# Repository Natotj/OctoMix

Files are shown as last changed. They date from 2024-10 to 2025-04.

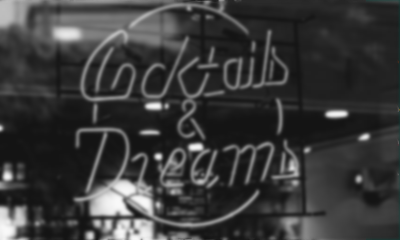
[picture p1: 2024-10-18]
Main_Programming/Display/Design_Elements/Symbols/Hintergrund weichgezeichnet.png

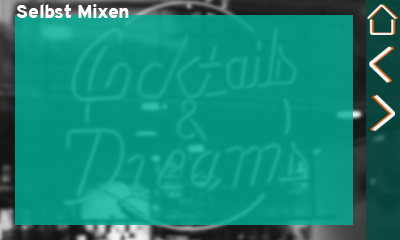
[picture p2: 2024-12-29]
Main_Programming/Display/Design_Elements/Pages/Self Mixing.png

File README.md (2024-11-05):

# OctoMix

Code and 3D parts for a diy cocktailmixer powerd by Arduino, EV3 and Nextion Dislplay. Many Parts are (or will be) 3D printed.

# NatotjEnglish.error

- Vent = valve

# Specs
- Arduiono Uno R3
- Lego Mindsorms EV3 31313
  - With 2 motors from the Lego Mindsorms NXT
  - Build with many other Lego technic parts
  - Programmed with the EV3 Lab (https://education.lego.com/de-de/downloads/retiredproducts/mindstorms-ev3-lab/software/)
- Nextion Display NX4024K032_011

# Disclaimer

All the content from this repo is for private use only. Use at your own risk!

# Contact

### E-Mail: 
- Natos.naz@gmail.com
- lama.customs@gmail.com

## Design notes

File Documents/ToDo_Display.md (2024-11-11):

### Cocktails

# Options 
- "selbst mixen" (mix yourself)
- Shots
- Pause, weiter, stopp (pause, continue, stop)
- zurück (back)

# Technical Options
- Ventil belegung (Doppelbelegung ausschließen) (valve assignment)
- Viskussität (von Standart) (viscosity)
- Glasgröße (glas size)
- Mixlänge (mix duration)

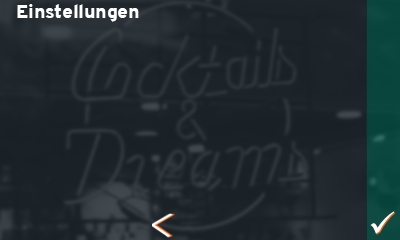
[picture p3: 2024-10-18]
Main_Programming/Display/Design_Elements/Pages/SET b.png

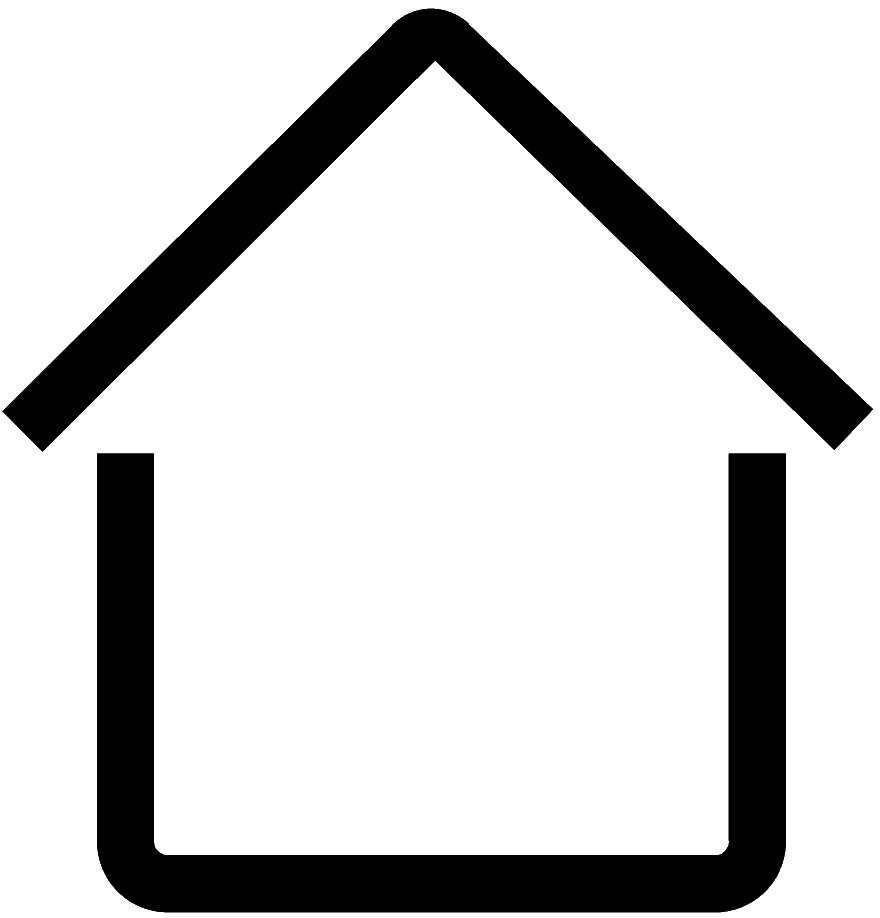
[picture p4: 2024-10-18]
Main_Programming/Display/Design_Elements/Symbols/Home.png

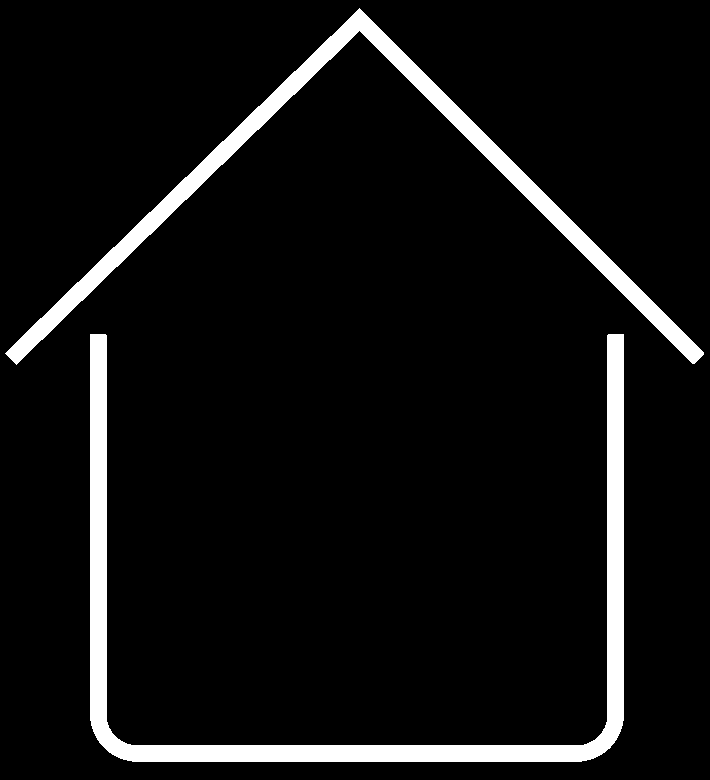
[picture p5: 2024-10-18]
Main_Programming/Display/Design_Elements/Symbols/Home.bmp

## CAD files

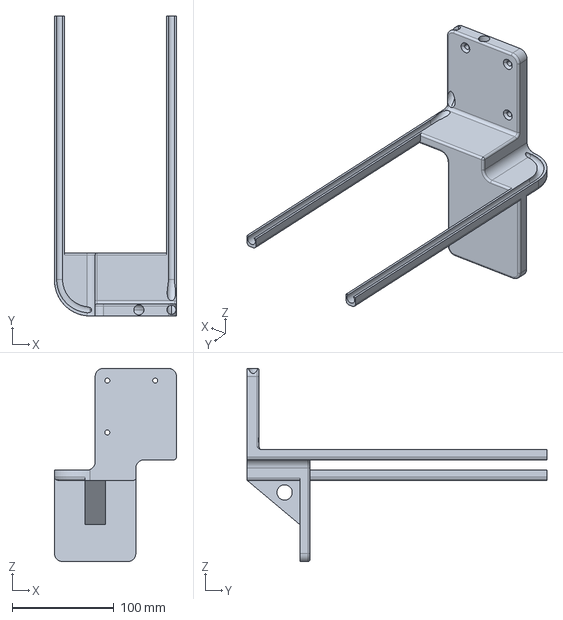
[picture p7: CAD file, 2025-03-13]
Main_Construction/3D-Print/flaschenhalter_asm.stp
120.0 x 295.0 x 190.0 mm

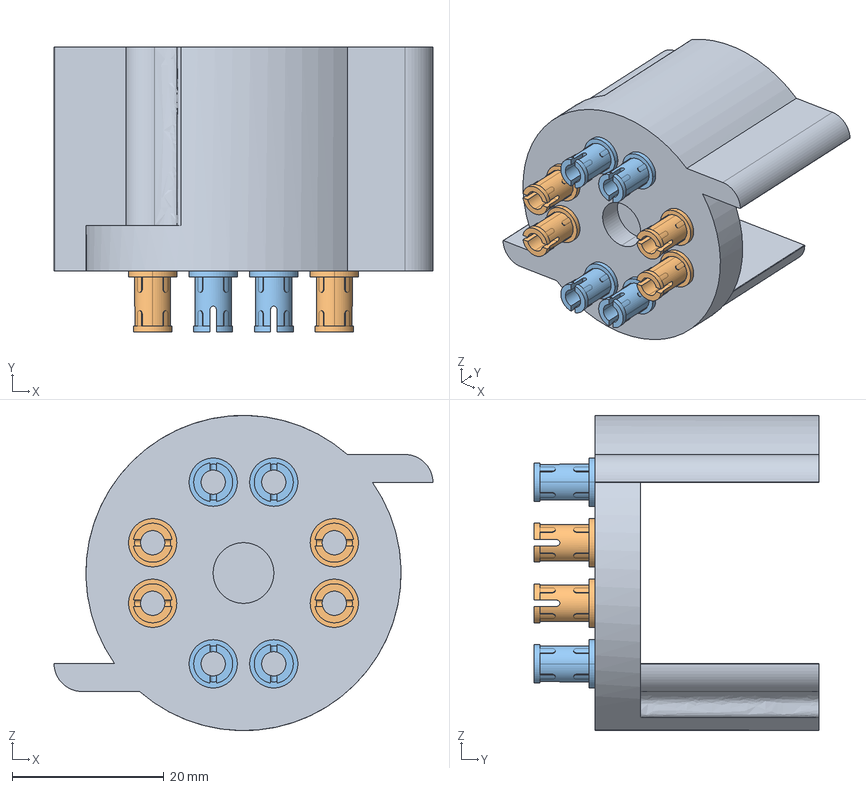
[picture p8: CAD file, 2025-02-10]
Main_Construction/3D-Print/ev3_zange_mit_pins_asm.stp
49.9 x 37.5 x 41.5 mm
EV3_ZANGE_AF0
LEGO_TECHNIC_FRICTION_PIN_AF0
LEGO_TECHNIC_FRICTION_PIN_AF1
LEGO_TECHNIC_FRICTION_PIN_AF2
LEGO_TECHNIC_FRICTION_PIN_AF3
LEGO_TECHNIC_FRICTION_PIN_AF4
LEGO_TECHNIC_FRICTION_PIN_AF5
LEGO_TECHNIC_FRICTION_PIN_AF6
LEGO_TECHNIC_FRICTION_PIN_AF7

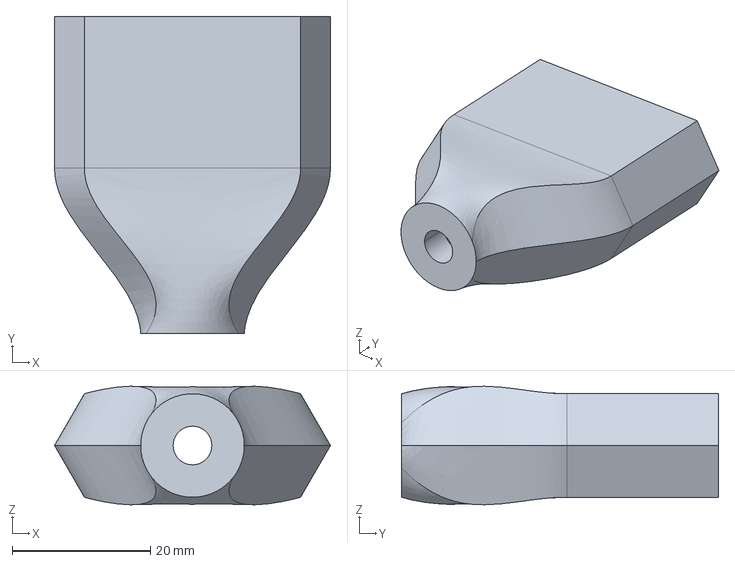
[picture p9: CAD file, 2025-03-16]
Main_Construction/3D-Print/schraubkopf.stp
40.0 x 46.0 x 17.2 mm

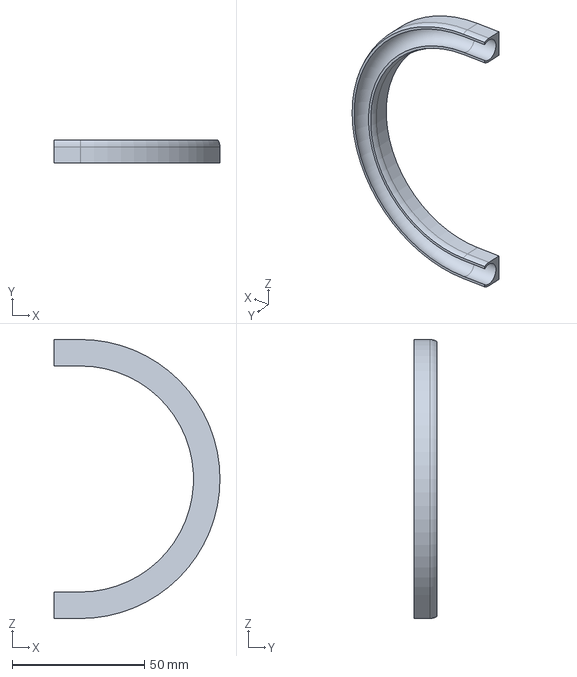
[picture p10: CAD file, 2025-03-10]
Main_Construction/Flaschenhalter/schlauchbogen.stp
62.7 x 8.50 x 105.3 mm

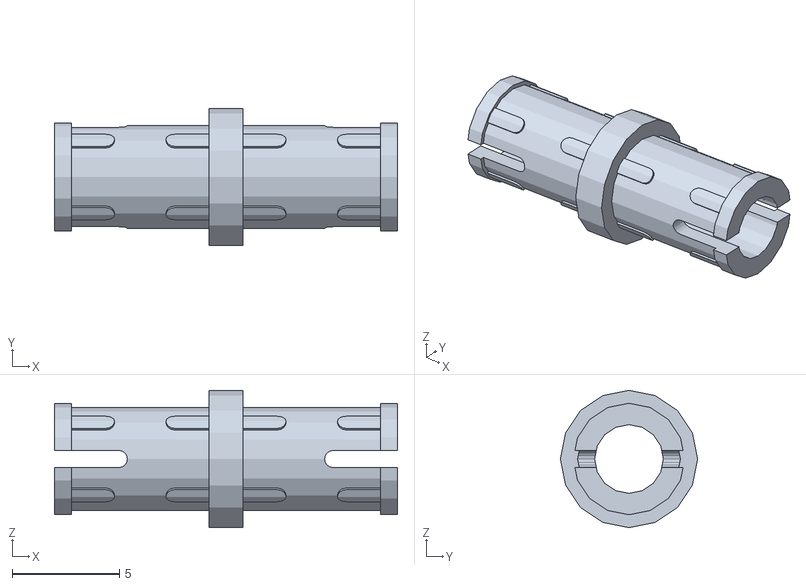
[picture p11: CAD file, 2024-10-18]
Main_Construction/Lego_tec_Pin_friction.stl
16.0 x 6.40 x 6.40

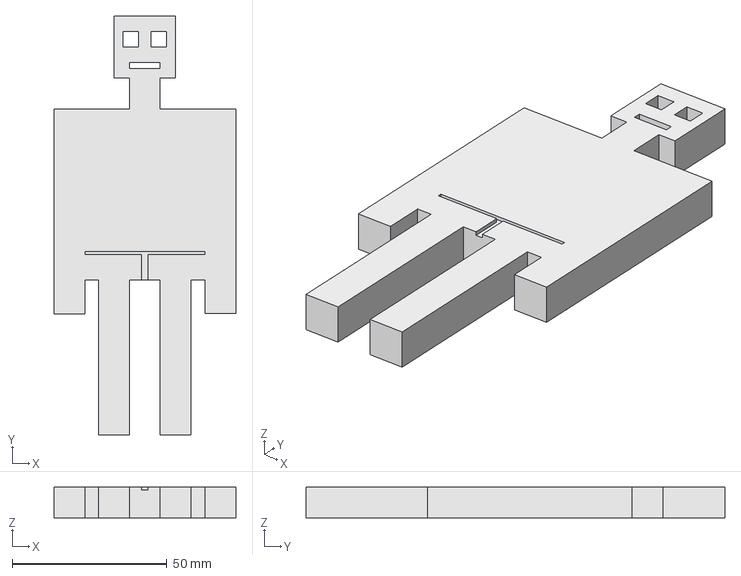
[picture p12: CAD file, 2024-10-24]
Main_Construction/TopSecret/alen.step
58.6 x 135.3 x 10.0 mm

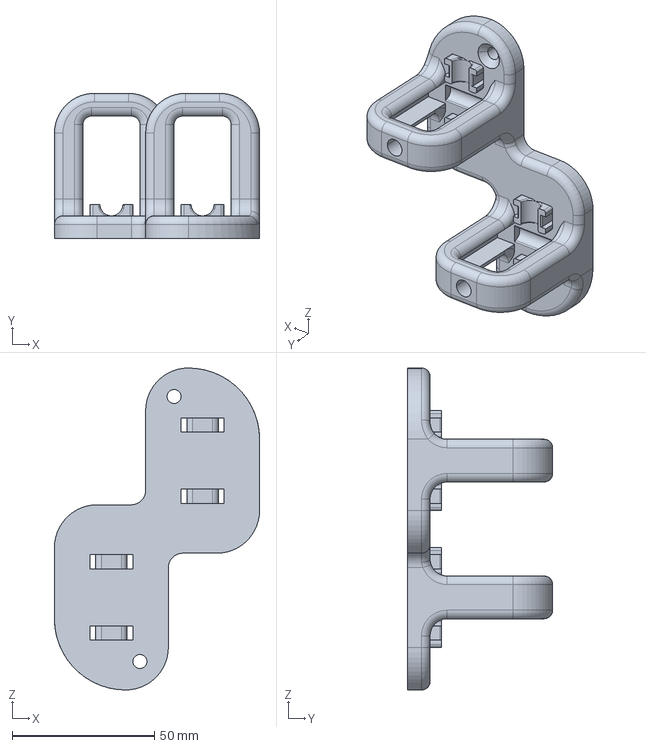
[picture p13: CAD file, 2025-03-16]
Main_Construction/3D-Print/valve_double_baseplate_v3.stp
72.0 x 51.0 x 113.0 mm

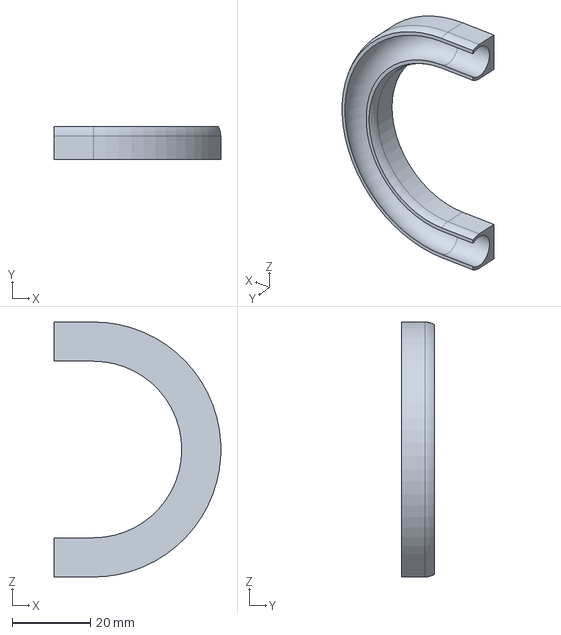
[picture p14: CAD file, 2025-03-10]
Main_Construction/3D-Print/schlauchbogen.stp
42.5 x 8.50 x 65.0 mm

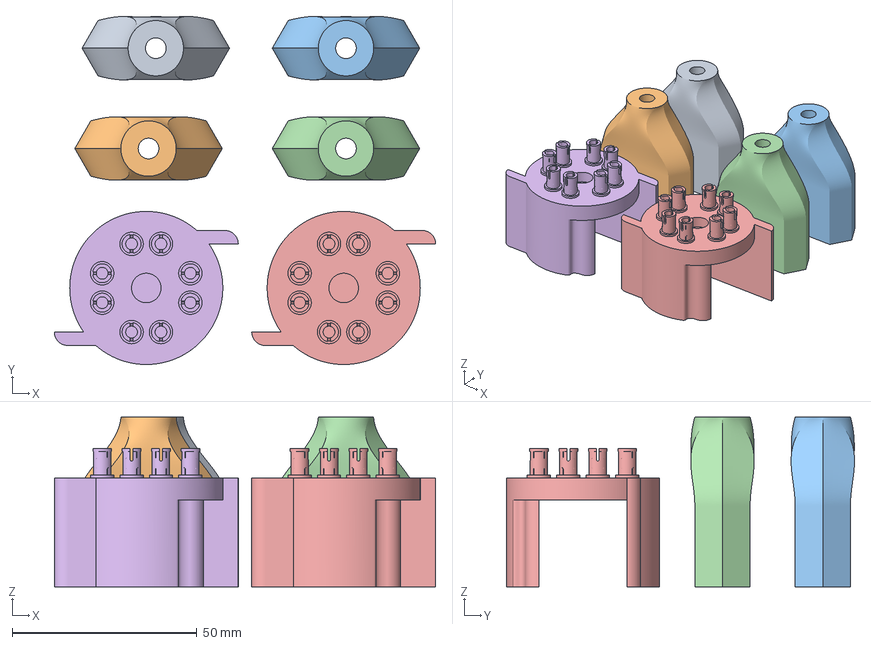
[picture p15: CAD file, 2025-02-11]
Main_Construction/3D-Print/EV3_Zange und Ventil Kopf.3mf
103.3 x 94.2 x 45.9 mm
schraubkopf
ev3_zange_mit_pins_asm

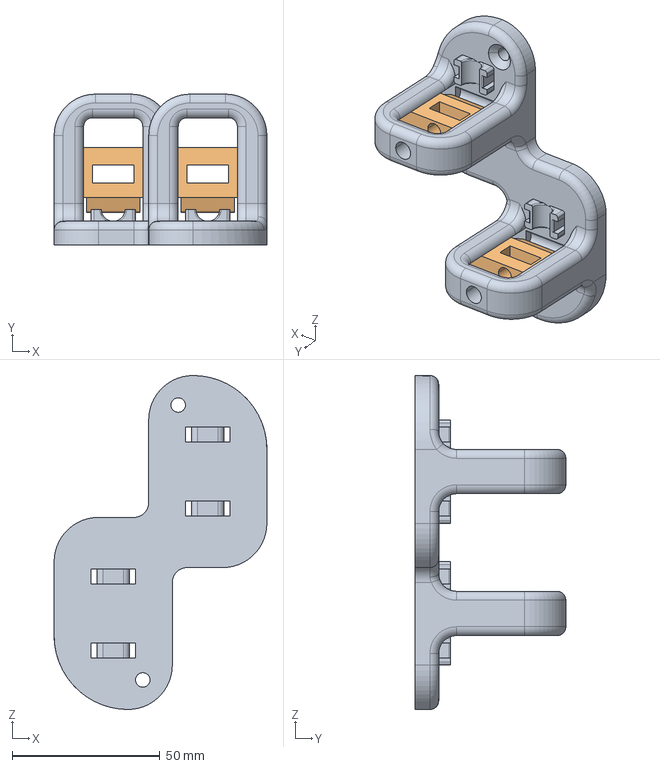
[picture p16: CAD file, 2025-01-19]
Main_Construction/3D-Print/Valve_V3.stp
72.0 x 51.0 x 113.0 mm
VALVE_DOUBLE_BASEPLATE
KLEMPLATTE_V3 x 2

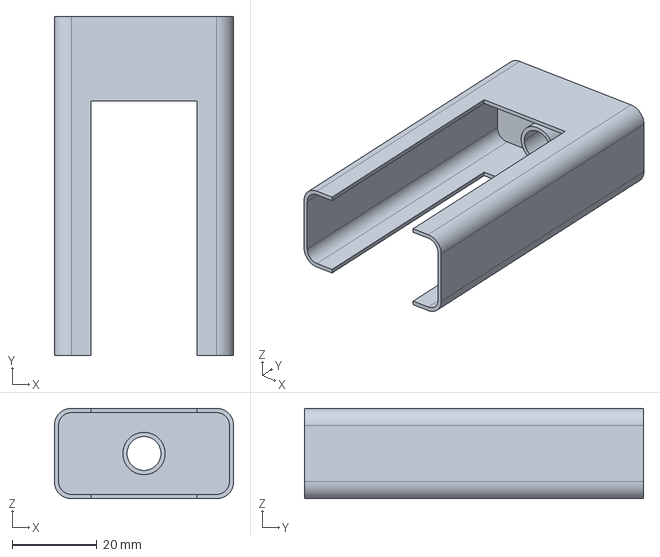
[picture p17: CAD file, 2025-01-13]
Main_Construction/3D-Print/montagehilfe_ltkol0001.stp
42.3 x 80.0 x 21.3 mm

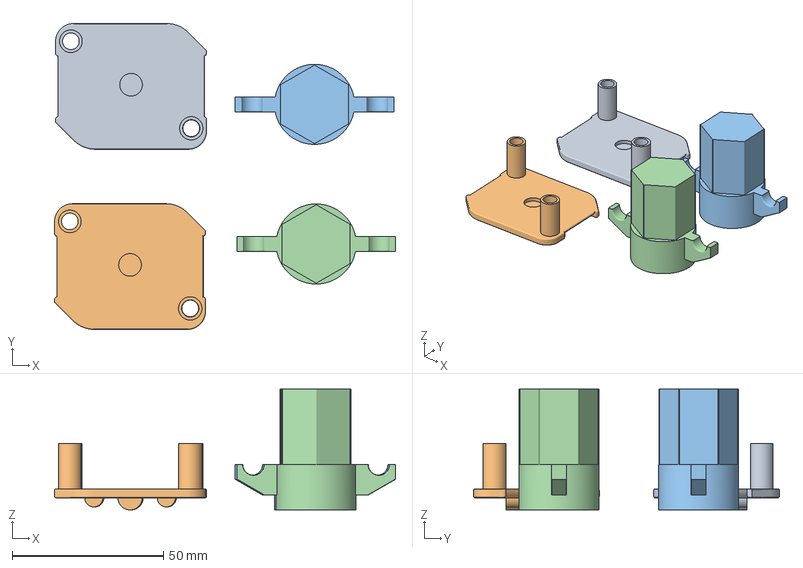
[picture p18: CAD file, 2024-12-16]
Main_Construction/3D-Print/Double Valve all components.3mf
112.7 x 101.1 x 40.0 mm
valve_clampplate
valve_head

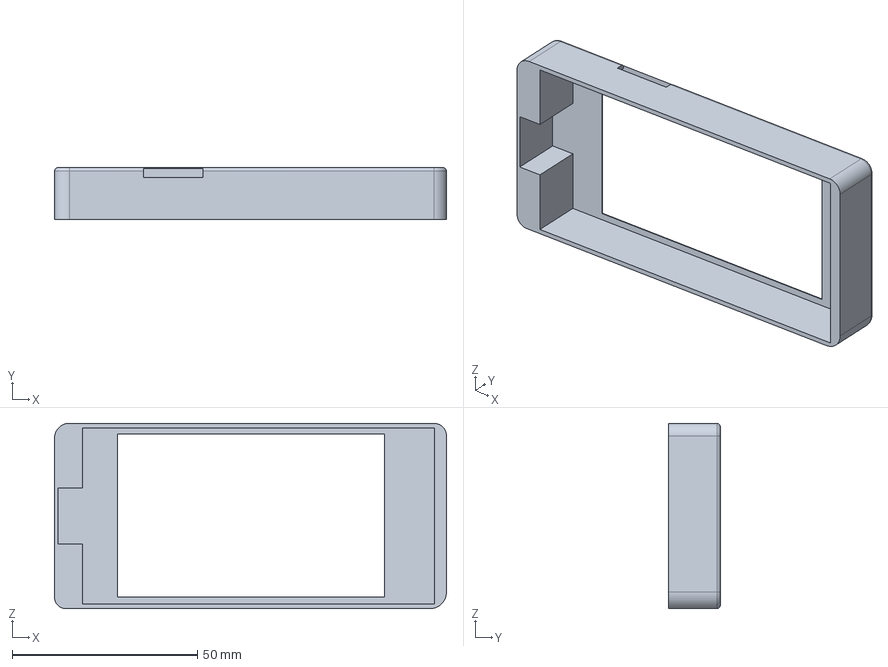
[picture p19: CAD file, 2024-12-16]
Main_Construction/3D-Print/display_braket.stp
105.7 x 14.0 x 50.0 mm

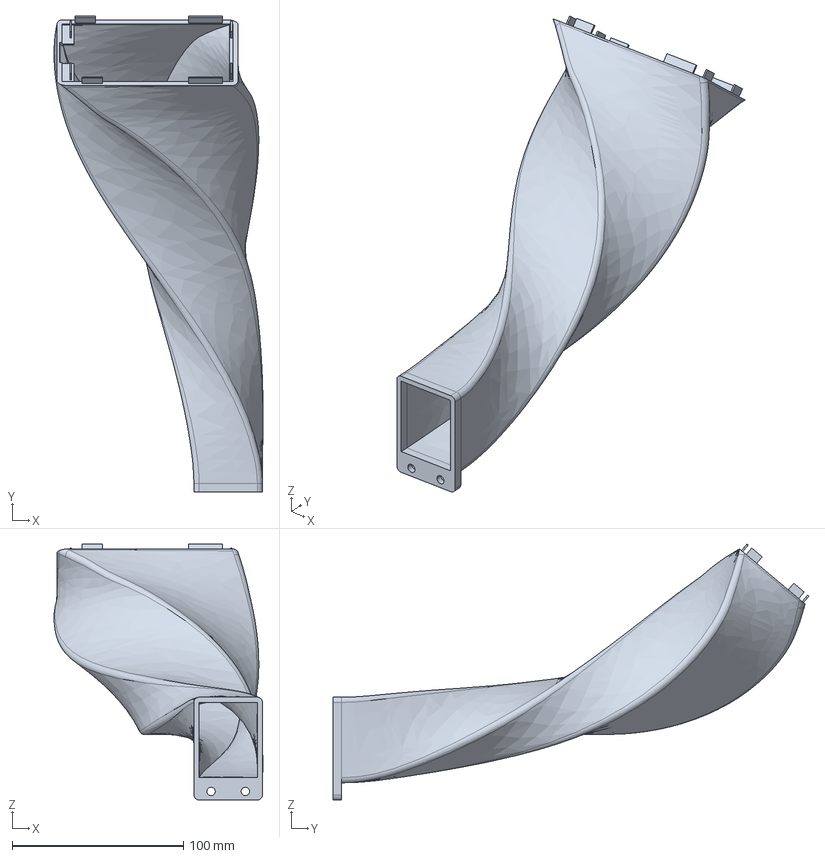
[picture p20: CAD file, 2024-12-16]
Main_Construction/3D-Print/hmi.stp
122.0 x 277.9 x 149.4 mm

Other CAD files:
Main_Construction/3D-Print/montagehilfe_loetkolben.3mf
Main_Construction/3D-Print/Double Valve white.3mf
Main_Construction/3D-Print/ultrasonic_hc-sr04_-_face_mount.stp
Main_Construction/3D-Print/ev3_stop.stp
Main_Construction/3D-Print/Ultrasonic_Mount_upper_part.stp
Main_Construction/3D-Print/Valve_V3.3mf
Main_Construction/3D-Print/ev3_stop and Display braket and HMI top part.3mf
Main_Construction/3D-Print/flaschenhalter_asm.3mf
Main_Construction/3D-Print/hmi-top-part.stp
Main_Construction/3D-Print/ultrasonic_hc-sr04_-_face_mount.3mf
Main_Construction/TopSecret/alen.FCStd
Main_Construction/Ultrasonic_HC-SR04_-_FACE_MOUNT.stl

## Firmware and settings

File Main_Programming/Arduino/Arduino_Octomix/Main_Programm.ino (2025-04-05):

//////////////////////////////////////////////////////////////
//          Main Program wich needs to be run
/////////////////////////////////////////////////////////////
// lokale Variablen
int i = 0;

void loop() {

//// Standby
  Display_Com();
  EV3_Com(EV3_STOP);
  EV3_Distance();
  temperatureRead();

int a[6] = {6, 8, 5, 9, 7, 10};
  while(true){
    for(i=0; i<6; i++){
      Serial.println(a[i]);
      Distance_Controll(valveDistance[a[i]-1]);
      //Distance_Controll(valveDistance[5-1]);
      Serial.println("angekommen");
      delay(2000);
      /*Distance_Controll(valveDistance[7-1]);
      Serial.println("angekommen");
      delay(2000);*/
    }
  }
// Programm zu Testzwecken für den Main Ablauf
  if(testRun == true){
   crsMix[0] = 0xF;  //15
    crsMix[1] = 0x4;  //04
    crsMix[2] = 0x15; //21
    crsMix[3] = 0x2; //02
    crsMix[4] = 0xE; //14
    crsMix[5] = 0x04; //04
    crsMix[6] = 0x1B; //27
    crsMix[7] = 0x5; //05
    crsMix[8] = 0x3; //03
    crsMix[9] = 0x14; //20
    crsMix[10] = 0x0; //0
    crsMix[11] = 0x0; //0
    crsMix[12] = 0x0; //0
    crsMix[13] = 0x0; //0
    crsMix[14] = 0x0; //0
    crsMix[15] = 0x0; //0
    crsMix[16] = 0x4; //4
    crsMix[17] = 0x0; //0
    isMixing = true;
  }

//// Ablauf Cocktail Mixen

  if(isMixing == true){ // Wenn Cocktail gemixt werden soll. isMixing wird von Display_Com gesetzt.
    //wann shaken?
    shake1 = crsMix[15];
    shake2 = crsMix[16];

    Progress_Bar();

    for(i=0; i<14; i+=2){ //stimmt die 14??
      printLine("New V");

      valveNum = crsMix[i];
      volume = crsMix[i+1];

      if (valveNum != 0){
        //zum Ventil fahren
        if(testRun == false) Distance_Controll(valveDistance[(valveNum+1)/2]); // gibt den aufgerundeten halbierten wert an valveDistance weiter an distance controll um dorthin zu fahren
        else Expanded_delay(5*1000);

        printLine("am Vent");
        Progress_Bar();  

        valveMove(valveNum); //Ventil öffnen
        Progress_Bar();
      
        //Pumpe
        digitalWrite(PUMP, HIGH); // Pumpe anschalten
        Expanded_delay(volume/flowrate * 1000); // richtige Zeit warten
        digitalWrite(PUMP, LOW); //Pumpe ausschalten
        Progress_Bar();
       
        valveMove(valveNum); //Ventil schließen
        Progress_Bar();

        //Shanken Wenn i/2+1=shake1 oder =shake2 dann shaken
        if((i/2+1)==shake1 || (i/2+1)==shake2) {
          digitalWrite(SHAKER, HIGH); // shaken an
          Progress_Bar(); 
          Expanded_delay(10*1000); // watet bis i größer als die wartezeit ist. (x in sek * 1000)
          digitalWrite(SHAKER, LOW); // shaken aus
        }
      }
    }
    // Nachricht an Display, dass Cocktail fertig
    Display_Write_Number("Home.isMixing.val=", 0);
    isMixing = false;
  }

  if(uploadToNextionDisplay == true) upload_to_display(); //Upload a Program to the Nextion display

  //Programm zum Testen von LED Werten der Übertragung
    /*while(true){
        delay(4000);
      int i;
      for(i=0; i < 9; i++) {
        analogWrite(LED, EV3_COM[i]);
        Serial.println(i);
        delay(4000);
      }
    }*/
}

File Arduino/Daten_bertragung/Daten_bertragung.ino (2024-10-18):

#define LCD_RS 4
#define LCD_E 7
#define LCD_D4 8
#define LCD_D5 9
#define LCD_D6 10
#define LCD_D7 11
#define JSTICK_VRX 3
#define JSTICK_VRY 4
#define JSTICK_SW 2
#define LED 6
#define USONIC_TRIG 1
#define USONIC_ECHO 0

int a[11]={0, 2, 7, 11, 15, 21, 35, 60, 95, 140, 255};
// EV3 Werte: 3-5, 8-10, 12-14, 15-17, 18-20, 23-25, 28-31, 33-35, 38-40, 44-46
// Befehle: 0 - STOPP
//          1 - Vorwärts schnell
//          2 - Vorwärts mittel
//          3 - Vorwärts langsam
//          4 - Rückwärts schnell
//          5 - Rückwärts mitttel
//          6 - Rückwärts langsam
//          7 - Ventil rear open
//          8 - Ventil front open
//          9 - Ventil rear close
//         10 - Ventil front close
//int a[10]={3, 10, 22, 40, 64, 93, 127, 165, 207, 255}; alte werte
int w=0;
String save="";
String save2="";
int test=0;
void setup() {
  // put your setup code here, to run once:
  Serial.begin(9600);
  pinMode(LED, OUTPUT);
  delay(5000);
}

void loop() {
  // put your main code here, to run repeatedly:
  /*
  Serial.println("vor"); //vor
  analogWrite(DIODE_ROT, 7);
  delay(1000);

  Serial.println("0"); 
  analogWrite(DIODE_ROT, 0);
  delay(500);

  Serial.println("Ventil 1");
  analogWrite(DIODE_ROT, 80);
  delay(1000);

  Serial.println("0");
  analogWrite(DIODE_ROT, 0);
  delay(500);


  Serial.println("zurück"); //zurück
  analogWrite(DIODE_ROT, 25);
  delay(1000);
  
  Serial.println("Ventil 2");
  analogWrite(DIODE_ROT, 200);
  delay(1000);

    Serial.println("0");
  analogWrite(DIODE_ROT, 0);
  delay(500);
*/
//analogWrite(LED, a[7]);
delay(500);
  for(int i=0; i<=10; i++)
  {
    //i=random(0,10);
    analogWrite(LED, a[i]);
    delay(5000);
    analogWrite(LED, 0);
    Serial.print(i);
    Serial.println();
    delay(50);
  } 
/*  if(Serial.available()>0)
  {
    while(Serial.available()>0)
    {
      w=Serial.read();
      w=w-48;
      save+=w;
      delay(30);
    }
    w=save.toInt();
    save="";
    analogWrite(LED, w);
    Serial.print("LED auf Wert:");
    Serial.println(w);
  }
*/

}

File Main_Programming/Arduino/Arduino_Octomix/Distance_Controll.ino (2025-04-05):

void Distance_Controll(float setPoint) {
  //Funktion um den EV3 über das gewünschte Ventil zu fahren. setPoint gibt den gewünschten Abstand zwischen US-Sensor und EV3 an. deltaErlaubt steuert die zulässige abweichung.
// PID-Parameter
  float Kp = 0.43*1.5;
  float Ki = 0.14*1.5;
  float Kd = 0.43*1.5;

//Variablen für den Regler
  float is; // ist wert vom US-Sensor
  float error = -2000; // Fehler
  float out = 0; // Regler ausgabe
  float lastIs = 0; //vorheriger Messwert
  float deltaErlaubt = 0.25; //Erlaubte Abweichung der Positionierung in cm
  float dt = 0.184; //mittelwert wenn EV3 in der Mitte steht
  int onSpot = 0; //Zähler damit der Regler nicht abbricht sobald zufällig eine passende Messung kommt
  
  bool ersterDurchlauf = true;

// Anteile vom Regler
  float proportional = 0;
  float integral = 0; 
  float differential = 0;


  //while(abs(error) > deltaErlaubt){
  while(onSpot < 10){ //erst wenn Regler noch 10 mal am richtigen platz geregelt hat geht es weiter
    Display_Com(); //um die kommunikation mit dem Display aufrecht zu erhalten
    is = EV3_Distance();
    error = setPoint - is;
    //Serial.println(error);
    if(abs(error) < deltaErlaubt) onSpot++; //wird immer hoch gesetzt wenn possition stimmt, verhindert zufällige gute Messungen

    if(ersterDurchlauf) { //Bei erstem Durchgang des Reglers 
      lastIs = is;
      ersterDurchlauf = false;
    }

    proportional = Kp * error;
    integral += error * dt;
    integral = constrain(integral, -15, 15);
    differential = (is - lastIs) / dt;

    out = proportional + (Ki * integral) - (Kd * differential);
    
    //übersetzen in EV3 Befehle
      if(out < 0){ 
        out = abs(out);
        if(out > 15){ // schnellstes Fahren
          EV3_Com(EV3_FW_F);
        }else if(out > 5){ // mittleres Fahren
          EV3_Com(EV3_FW_M);
        }else { // langsames Fahren
          EV3_Com(EV3_FW_S);
        }
      }else{
        if(out > 15){ // schnellstes Fahren
          EV3_Com(EV3_B_F);
        }else if(out > 5){ // mittleres Fahren
          EV3_Com(EV3_B_M);
        }else { // langsames Fahren
          EV3_Com(EV3_B_S);
        }
      }

    lastIs = is; 
  }
  EV3_Com(EV3_STOP);
  onSpot = 0;
}

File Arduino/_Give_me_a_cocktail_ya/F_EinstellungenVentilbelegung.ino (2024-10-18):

void EinstellungenVentilbelegung() //ScreenEbene = 2
{
  ResetVariablen();
  
  lcd.clear();
  lcd.setCursor(1,0);
  lcd.print((String)Zutatenkoordinate[CursorY]+" "+ Zutatennamen[CursorY]);
  lcd.setCursor(1,1);
  lcd.print((String)Zutatenkoordinate[CursorY+1]+" "+ Zutatennamen[CursorY+1]);
  lcd.setCursor(0,0);

  while(ScreenEbene != 9)
   {  
     
     while(JStick_Push == false)
      {
        DisplayScroll(Zutatennamen, Zutatenanzahl, true, Zutatenkoordinate, 0, 0);
      }
    
    JStick_Push = false; //Zurücksetzen
  
  
     if (CursorY != 0) //also nicht auf return
      {
        int SaveCursorY = CursorY; //sichert die Auswahl
        CursorY = Zutatenkoordinate[SaveCursorY];
        lcd.setCursor(1,0);
        
          while(JStick_Push == false)
          {
            JStick(Ventilzahl, 1);
        
            delay(300);
            
            lcd.setCursor(1,0);
            
            if (CursorY <= 9 && CursorY >= 0) lcd.print((String)CursorY+ " " +Zutatennamen[SaveCursorY]); //fügt leerzeichen hinzu wenn zahl einstellig
            else lcd.print((String)CursorY + Zutatennamen[SaveCursorY]);
        
            lcd.setCursor(1,0); //damit der Cursor wieder da is wo er soll und nicht am Ende der Zeile
          }
        JStick_Push = false;
        Zutatenkoordinate[SaveCursorY] = CursorY;
        CursorY = SaveCursorY;
        lcd.setCursor(0,0);
      }
    else
      {
        ScreenEbene = 9;
      }
      
   /* lcd.clear();
    lcd.setCursor(1,0);
    if (CursorY <= 9 && CursorY >= 0) lcd.print((String)Zutatenkoordinate[CursorY]+" "+ Zutatennamen[CursorY]); //fügt leerzeichen hinzu wenn zahl einstellig
    else lcd.print((String)Zutatenkoordinate[CursorY]+ Zutatennamen[CursorY]);
    lcd.setCursor(1,1);
        if (CursorY <= 9 && CursorY >= 0) lcd.print((String)Zutatenkoordinate[CursorY++]+" "+ Zutatennamen[CursorY++]); //fügt leerzeichen hinzu wenn zahl einstellig
    else lcd.print((String)Zutatenkoordinate[CursorY++]+ Zutatennamen[CursorY++]);
    lcd.setCursor(0,0);*/
    

     }
}

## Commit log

2024-10-18 Typo corrected: SerialConection -> SerialConnection && SerialConnection.ino; SerialConnection.ino: Small change, out=crs[ID-1] instead of ID--;.
    [SerialConection.ino]
2024-10-20 Ordnerstruktur verbessert und Dokumentation angelegt
    [Lego_tec_Pin_friction.stl, Wertetabelle senden_Abnehmen.xlsx, valve_clampplate.3mf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]
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2024-10-22 Update README.md. Please enter specs from various devices @Natotj (Arduino, Display & co.)
2024-10-23 Improved folder structure and translating foldernames to english && Display: Homepage: Settings button now has a red background for way better visibility (I almost missed the button entirely)!
    [Lego_tec_Pin_friction.stl, Wertetabelle senden_Abnehmen.xlsx, valve_clampplate.3mf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]
2024-10-24 Top Secret Classified
    [alen.FCStd, alen.step]
2024-11-02 Renameing: Übersicht und Rezepte.xslx -> CocktailRecipes.xlsx.
    [CocktailRecipes.xlsx]
2024-11-02 Renamed and cropped the Picture for the display mount.
2024-11-04 Tried to add password to the settings. Always goes back after 500ms because of the timer. Had a fix but didn't quite work.
2024-11-14 Konstruction work
    [Stützen links und rechts.3mf, push_pull_block.3mf, push_pull_block.stp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]
2024-11-15 Three SelfMix pages were added with the according buttons. Test Text is not being display. I dont know why.
2024-11-16 file management of Construction files
    [Stützen links und rechts.3mf, push_pull_block.3mf, push_pull_block.stp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]
2024-11-16 Elements added to prevent the EV3 from falling off the rails
2024-11-17 Added a braket for the ultasonic posistion sensor
    [Ultrasonic_HC-SR04_-_FACE_MOUNT.stl]
2024-11-18 Display braket added
    [Lego_tec_Pin_friction.stl, Ultrasonic_Mount_upper_part.stp, display_braket.stp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]
2024-11-18 filename changed
    [Ultrasonic_Mount_upper_part.stp, display_braket.stp, ev3_stop.stp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]
2024-11-20 Konstruktion und verbesserung von HMI und halterung Ultraschallsensor.
    [display_braket.stp, display_braket_Ultrasonic_upper_part_EV3_stop.3mf, ev3_stop and Display braket and HMI top part.3mf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]
2024-11-20 deleted unessesary data
    [display_braket_Ultrasonic_upper_part_EV3_stop.3mf, hmi-top-part and display braket.3mf, hmi_and_ultrasonic_senosr_asm.stp]
2024-12-06 Changes to the valve design and producing 3D printing files
    [Double Valve all components.3mf, ultrasonic_hc-sr04_-_face_mount.3mf, ultrasonic_hc-sr04_-_face_mount.stp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]
2024-12-11 Update design and printing of the Valves
    [Double Valve white.3mf, valve_clampplate.stp, valve_double_baseplate.stp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]
2024-12-16 first real world tries with Arduino and EV3. Software updates, tests and bug fixes
    [Double Valve all components.3mf, display_braket.stp, hmi.stp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]
2024-12-17 Combined current program funcitions in one Arduino Script
2024-12-20 Added a PI Contorller to the Arduino to possition the EV3 via an optocouplter Comunication
2024-12-23 Arduino Code to upload Code to the Nextion Display via a Serial Connection and increased the boud rate. This was nessesary due to SD card malfunctions
2024-12-23 Changes on the comunication between Arduino and the Nextion Display
2024-12-24 Communication betwen Nextion displayn and Arduino is working! Also added a flowchart to the Arduino main Program.
    [CocktailRecipes.xlsx]
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2024-12-30 fixed coding issue with sizeof() function and worked on the nextion display
    [Display_Com.ino]
2025-01-03 Fixed a bug in (Display_Com) and some minor bugs in the Nexiton program
    [Arduino_Octomix.ino, Display_Com.ino]
2025-01-04 Display_Write hopefully fixed. The issue seemed to be wrong printed quotation marks.
    [Display_Com.ino]
2025-01-06 Display_Write was replaced by Display_Write_Number and Display_Write_String. That way the marks should hopefully be at the right place.
    [Arduino_Octomix.ino, Display_Com.ino, Progress_Bar.ino]
2025-01-06 Display_Write occurences corrected to Display_Write_Number or Display_Write_String.
    [Arduino_Octomix.ino, Display_Com.ino]
2025-01-07 small fixes to the display write functions
    [Display_Com.ino]
2025-01-07 small error correction and implementation of (Display_Write_Number) and (Display_Write_String) to allow instructions send easily to the Nextion Display
    [Arduino_Octomix.ino, Display_Com.ino, Progress_Bar.ino]
2025-01-07 Small change: Arduino Start is now printed in a new line for a better appearance.
2025-01-08 Typo fixed (Resart -> Restart). Couldn't find any reason, why the recepies are not being displayed. The Display_Write_String function outputs the String from the array properly.
    [Display_Com.ino]
2025-01-08 Fixed Bug caused by to many (Serial.print) commands. Probably because the Flash memory is full
    [Arduino_Octomix.ino, Display_Com.ino, Main_Programm.ino]
2025-01-08 bug fixing and works on the Main program
    [Arduino_Octomix.ino, Display_Com.ino, Distance_Controll.ino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]
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2025-01-12 Desing work on the Valve version 3.0 and construction of an mounting tool. 3D printing files created. Not jet implemented into the Main construction
    [Valve_V3.3mf, Valve_V3.stp, montagehilfe_loetkolben.3mf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]
2025-01-12 Progress_Bar.ino: lenArray is now corrected (subtraction -1 to get rid of the null string-terminator) && if statement: crsMix != '0' insted of 0.
    [Progress_Bar.ino]
2025-01-13 Finalised the construction of Valve V3 and implemented the design in the Main Construction
    [Valve_V3.stp, montagehilfe_loetkolben.3mf, montagehilfe_ltkol0001.stp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]
2025-01-14 Bug Fix Progress_Bar.ino: Should now work. Had to declare the mixSteps int to static. That's why the progress would go into the negativ numbers before, because mixSteps was set to 0 in case 0.
    [Progress_Bar.ino]
2025-01-14 Contruction Work on Valve V3
    [Valve_V3.3mf]
2025-01-16 Hopefully final tweaks of Progress_Bar.ino. Fixed the percentAdd variable calculation (was automataclly rounded to an integer because of the 100/ instead of 100.0/). mixSteps is also global now (Im n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
    [Progress_Bar.ino]
2025-01-18 Progress_Bar.ino: Progress is now rounded later when it's send to the arduino. That way the Progress gets to 100 (& doesn't go over) and can be properly reset.
    [Arduino_Octomix.ino, Progress_Bar.ino]
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2025-01-19 Detailed the construction of Valve V3
    [Valve_V3.3mf, Valve_V3.stp, schraubkopf.stp]
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2025-01-20 Progress_Bar.ino: Further testing. Reduced the number needed for a reset from 100 to 99. Otherwise crsMix with a small amount of mixSteps (~3) or with a bigger amount of mixSteps (~9) wouldn't work r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
    [Progress_Bar.ino]
2025-01-21 Some reworked comments in Progress_Bar.
    [Display_Com.ino, Progress_Bar.ino]
2025-01-29 File Utils added: Used for small functions. writeLine() added (uses Serial.write for better performance instead of Serial.println)
2025-01-29 Replaced Serial.println with writeLine() or Serial.print with Serial.write where it's possible.
    [Arduino_Octomix.ino, Main_Programm.ino]
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2025-02-04 Konstruction on the link between the EV3 and the Valve_V3. Also cleaned the workspace
2025-02-10 new 3D printing datas for the valve heads and the EV3 tongs
    [EV3_Zange und Ventil Kopf.3mf, ev3_zange_mit_pins_asm.stp, schraubkopf.stp]
2025-02-11 integrated a vent position reset to the EV3 start up sequence; Changes to the Arduino Code to use less Serial commands since this made up not further understandable Errors; Integrated the new Valev H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
    [EV3_Zange und Ventil Kopf.3mf]
2025-03-01 Progress_Bar(): mixSteps -> counting was off (x2) && make switch statement more readable. Progress Bar should now be functional!
2025-03-02 Progress_Bar() small formatting fix with the switch statement (<- brake).
    [Progress_Bar.ino]
2025-03-02 fixes to the main code including code to test the program
    [Arduino_Octomix.ino, Main_Programm.ino]
2025-03-05 Construction Work. New part for bottels to stand on
    [Valve_V3.3mf, flaschenhalter_asm.3mf, flaschenhalter_asm.stp]
2025-03-09 new Bottle holder and cleaning up the workspace
    [flaschenhalter_asm.3mf, flaschenhalter_asm.stp, schlauchbogen.stp]
2025-03-10 small bug fixes in the Bottle holder design
    [flaschenhalter_asm.3mf, schlauchbogen.stp]
2025-03-10 Minor changes to the 3D print of the Botle holder. Changes to the EV3 program to check if Moving is possible (not when Valves are open)
    [flaschenhalter_asm.3mf]
2025-03-10 Bug fixing the construction of the bottle holder. EV3 -> Vent_reset -> addition of an correction value to aligne the Valve heads after the position reset of the EV3 motors.
    [schlauchbogen.stp]
2025-03-10 Bug fix for the Arduino EV3 comunication. Tuning of the Force regulated Motor function of the EV3.
    [flaschenhalter_asm.3mf]
2025-03-13 bug fix in the Bottle holder
    [flaschenhalter_asm.3mf, flaschenhalter_asm.stp]
2025-03-14 3D printing of the Bottle holder
    [flaschenhalter_asm.3mf]
2025-03-16 new 3D printing files
    [Valve_V3.3mf, flaschenhalter_asm.3mf, schraubkopf.stp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]
2025-04-03 Changes to the EV3 program to check if the Arduino Signal for opening an Closing the Valves is valid or not.
    [Valve_V3.3mf, flaschenhalter_asm.3mf]
2025-04-03 Changes to the EV3 Arduino_Signal_Decoder to work with only 8 arduino Signals, for a more stable comunication
2025-04-03 Made Arduino Main Mixing code more readable. Added function ValveMove for that.
2025-04-03 Bug fixing and tuning of the closing sequences in the EV3, Valve front and reare.
    [EV3_Distance.ino, Main_Programm.ino]
2025-04-03 implementation of an temperature Sensor to compensate for variation of the speed of sound. Therfore i get more stable distance readings from the Ultrasonic Sensor, wich was an issue occuring between 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
    [Arduino_Octomix.ino, EV3_Distance.ino, Main_Programm.ino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]
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2025-04-05 Tuning of the PID-Control and adding an additional controll sequence-Varible after the EV3 has reached his spot, called onSpot
2025-04-27 Deleted cliScript.sh out of the root directory -> only belongs into Main_Programming/Arduino/Arduino_Octomix.
2025-06-11 Updated cliScript.sh -> now there is also a option to change the boardname and upload afterwards.
